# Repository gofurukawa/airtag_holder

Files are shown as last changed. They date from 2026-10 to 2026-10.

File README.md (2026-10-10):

# AirTag Umbrella Holder for AMVEL pentagon LARGE

AMVEL の超軽量折りたたみ傘 [pentagon LARGE](https://www.umbrella-store.net/products/pentagon-large)（[pentagon シリーズ](https://www.umbrella-store.net/collections/pentagon-series)）の持ち手の端に、AirTag を固定するための 3D プリント用ホルダーです。

持ち手の端にある円盤を左右 2 つのパーツで挟み込み、その下に AirTag を収め、窓あきのキャップをねじ込んで全体を固定します。

> [!NOTE]
> AMVEL 社とは関係のない非公式の自作パーツです。寸法は手元の 1 本を実測した値で、ロットや他モデル（pentagon72 / pentagon67 など）では合わない可能性があります。

## 構造

使用時の向き（上が生地側）で、上から次の順に重なります。

| 部品 | 役割 |
| --- | --- |
| 挟みパーツ A / B | 持ち手の円盤を左右から抱き込む。上端の爪でリム上端を押さえ、下部の外周におねじ |
| AirTag | 円盤の下のポケットに収納 |
| キャップ | めねじで本体にねじ込み、左右パーツを一体化。下向きの窓（Ø26）から AirTag が見え、音も抜ける |

設計上のポイントは次のとおりです。

- 円盤上面の凹みは、傘を畳むときに骨の連結部分が収まる場所なので、ふさがないようにしています。爪はリムの上端（幅約 1.35mm）だけを押さえ、凹みの開口 Ø26.8 はそのまま残ります。
- 円盤の底面は中央に向けてなだらかに膨らんでいます。実物は半径約 28mm の球面で、縁には幅約 1.5mm の平らな肩があります。空洞の底はそれよりわざと浅い球面（R33.7、縁の角と中央を通る球面）にしていて、円盤は爪・縁の角・中央の 3 か所で支えます。中央から縁の手前までに残る 0.5〜0.8mm のくさび形の空間は、印刷誤差と持ち手の個体差を吸収する余白です。実物の肩まで再現すると、空洞が設計より 0.2mm ほど狭く出るプリンタでは当たります。
- シャフト上の凹み（円盤上面から 13.5mm）や伸縮ロックのボタン（同 29.0mm）にはかかりません。
- 窓が下を向くので、入り込んだ雨水は自然に抜けます。
- 挟みパーツは合わせ面を下にして印刷するので、内側の空洞は横倒しのアーチになります。アーチの頂上（合わせ面から最も遠い所）は、45°の屋根と、元の円より 0.6mm 外側の平らな天井に置き換えています。この天井は両端が支えられた短い橋（ブリッジ）なので、サポートなしで印刷できます。少したれても、0.6mm の逃げの中に収まれば空洞には入り込みません。円盤と AirTag は、屋根の斜面と残りの円周で位置が決まります。

組み付け後の外形は、最大 Ø43.7mm、全高は約 22.5mm（円盤より下に約 11mm、上に 2mm）です。

## ファイル

| ファイル | 内容 |
| --- | --- |
| `airtag_umbrella_holder.scad` | OpenSCAD のソース。寸法はすべて変数 |
| `half_a.stl` | 挟みパーツ A（印刷向きに配置済み） |
| `half_b.stl` | 挟みパーツ B（印刷向きに配置済み） |
| `cap.stl` | キャップ（印刷向きに配置済み） |

## 実測値（モデルの基準寸法）

| 記号 | 箇所 | 値 |
| --- | --- | --- |
| A | 円盤の外径 | 29.5 mm |
| B | 円盤の厚み | 縁 5.6 mm / 中央 9.0 mm（底が膨らんでいる） |
| C | 凹みの内径（リム内径） | 26.8 mm |
| D | 凹みの深さ | 縁 4.6 mm〜（中央ほど深い） |
| — | 底面のふくらみ | 球面半径 約 28 mm。縁に幅約 1.5 mm の平らな肩（試し刷り品との隙間に名刺 0.5mm が入り 0.8mm が入らないこと、肩の幅から推定） |
| E | シャフト径 | 7.7 mm |
| — | リムの厚み | 約 1.35 mm |

## 部品の主な寸法

| 項目 | 値 |
| --- | --- |
| 爪の内径 | Ø26.8 mm |
| 円盤の空洞 | Ø29.9 mm、底は R33.7 の球面（片側 0.2mm のすき間）。縁と中央でぴったり固定できた実績のある値 |
| AirTag ポケット | Ø32.4 × 深さ 8.3 mm |
| 空洞の天井の逃げ | 45°の屋根＋元の円より 0.6 mm 外側の平らな天井（合わせ面と垂直な向きだけ） |
| ねじ | 台形ねじ Ø39 × ピッチ 3 mm、山の高さ 1.5 mm |
| キャップの窓 | Ø26 mm |
| 位置決めピン | Ø1.75 mm（フィラメント流用）× 2 本 |

## Mac で使うソフトウェア

### OpenSCAD（.scad を開いて寸法を調整する）

```sh
brew install --cask openscad@snapshot
```

正式版（2021.01）でも動きますが、ねじ山を含むこのモデルではレンダリング（F6）に数分かかります。開発版（snapshot）を入れ、Preferences → Advanced で Backend を **Manifold** にすると数秒で終わります。Apple Silicon にもネイティブ対応しています。

Homebrew の cask 名が変わっている場合は、[openscad.org](https://openscad.org/downloads.html) の Development Snapshots から直接ダウンロードしてください。

### スライサー（STL を確認して G-code にする）

| ソフト | 向いているプリンタ |
| --- | --- |
| [UltiMaker Cura](https://ultimaker.com/software/ultimaker-cura/) | Creality（Ender-3 S1 Pro など）、Ultimaker、汎用機 |
| [Bambu Studio](https://bambulab.com/download/studio) / [OrcaSlicer](https://github.com/SoftFever/OrcaSlicer) | Bambu Lab |
| [PrusaSlicer](https://www.prusa3d.com/page/prusaslicer_424/) | Prusa |

### インストール不要の確認方法

Finder で STL を選んでスペースキーを押すと、クイックルックで 3D プレビューを回して確認できます。

## STL の書き出し

OpenSCAD の GUI でカスタマイザーの `part` を切り替えて F6 → F7 で書き出すか、コマンドラインで次のように実行します。

```sh
# macOS（Homebrew cask）の場合、openscad コマンドはアプリ内にある
OPENSCAD=/Applications/OpenSCAD.app/Contents/MacOS/OpenSCAD

for p in half_a half_b cap; do
  "$OPENSCAD" -D "part=\"$p\"" -o "$p.stl" airtag_umbrella_holder.scad
done
```

アプリ名が `OpenSCAD-Nightly.app` などになっている場合は、パスを読み替えてください。

| `part` の値 | 出力 |
| --- | --- |
| `assembly` | 傘と AirTag のダミー入りの組み付け確認用 |
| `half_a` / `half_b` | 挟みパーツ（印刷向き） |
| `cap` | キャップ（印刷向き） |
| `print_all` | 3 部品を並べた状態 |

## 印刷設定（Creality Ender-3 S1 Pro + Cura 5.13 の例）

Cura のプロファイル「Standard Quality」を元に、次のように設定します。括弧内は Cura の英語表示の項目名で、設定パネル上部の検索欄に入れると見つかります。

| 設定 | 値 | 理由 |
| --- | --- | --- |
| ノズル径（Nozzle） | 0.4 mm | 標準 |
| 積層ピッチ（Layer Height） | 0.16 mm | ねじ山をなめらかにする |
| 壁の線数（Wall Line Count） | 4 | ねじ部（肉厚約 1.8mm）をほぼソリッドにする |
| インフィル密度（Infill Density） | 20%（初期値のまま） | 壁 4 本で部品のほとんどが埋まり、インフィルが入る所はほとんどない（下記） |
| サポート（Generate Support） | オフ | 3 部品ともサポートなしで印刷できる。オンにすると空洞の平らな天井の下にサポートが入る |
| ブリッジ設定（Enable Bridge Settings） | オン | Standard Quality では初期値がオフ。オンにすると、空洞の天井（ブリッジ）だけ速度と冷却を調整し、糸を張るように渡す |
| ブリッジのファン速度（Bridge Fan Speed） | 100% | ブリッジ設定をオンにすると表示される。渡した糸をすぐ固めて、たれを抑える |
| 初期層水平展開（Initial Layer Horizontal Expansion） | -0.1〜-0.2 mm | 1 層目がつぶれて広がり（エレファントフット）、合わせ面のふちが空洞側やねじ側へはみ出すのを防ぐ |
| 向き | STL のまま | 挟みパーツは合わせ面が下（ねじ山が上）、キャップは底面が下 |

- 挟みパーツは合わせ面を下にして印刷します。下を向く面は空洞の 45°の屋根と短い橋、ピン穴の小さな天井だけなので、サポートは要りません。合わせ面がベッドで平らに仕上がり、定着も安定します。
- この向きだと、ねじ山と爪にかかる力（ねじの軸方向）が積層面に沿うので、層間で割れにくくなります。
- ピン穴はベッドから垂直に立つ穴になり、真円に出ます。
- 空洞の天井は、PrusaSlicer 2.7 でスライスするとブリッジとして処理され、渡す長さは次のとおりでした。円盤の空洞は四方が囲まれているので、スライサーが短い向き（ねじの軸方向）を選びます。

  | 天井 | 渡す向き | 長さ |
  | --- | --- | --- |
  | AirTag ポケット | ねじの軸と直角 | 約 12 mm |
  | 円盤の空洞 | ねじの軸方向 | 約 6 mm |
  | 爪の開口 | ねじの軸と直角 | 約 10 mm |

- ブリッジの下面（空洞の内側）は糸が少したれたり波打ったりしますが、円盤や AirTag には触れない面なので、そのままで構いません。たれが 0.6mm を超えて円盤や AirTag が窮屈になるときは、`bridge_relief` を増やします（下の「調整」を参照）。
- キャップはサポートなしで印刷できます。
- インフィル密度はほぼ効きません。PrusaSlicer 2.7 で壁 4 本・インフィル 20% でスライスすると、インフィルの割合は使うフィラメントの 0.1%（挟みパーツ）と 5%（キャップ）でした。50% に上げても挟みパーツは変わらず、キャップが 4% 増えるだけです。
- 素材は、試し刷りなら PLA で十分です。常用するなら、熱や紫外線に強い PETG か ASA がおすすめです。PETG は PLA よりブリッジがたれやすいので、ブリッジの速度を落とすと安定します。

## 組み立て

1. 1.75mm フィラメントをニッパーで約 6mm に 2 本切り、バリを落とします。
2. 挟みパーツの片方の合わせ面にあるピン穴に、ピンを差し込みます。
3. 左右のパーツで持ち手の円盤を挟みます。
4. 下側のポケットに AirTag を入れます。
5. キャップをねじ込みます。キャップは本体の下端に突き当たって止まり、AirTag を押しつぶしません。

## 調整

試し刷りの結果に応じて、`.scad` の次の変数を変えてください。

| 症状 | 変数 | 目安 |
| --- | --- | --- |
| キャップがきつい／緩い | `thread_clr`（初期値 0.35） | きつければ 0.45、緩ければ 0.25 |
| 円盤にはめるとガタつく／閉じない | `clr`（初期値 0.2）、`recess_d`（爪の内径） | 0.1 刻みで調整 |
| 空洞の底を実物の肩まで再現したい | `dome_R`（初期値 0 ＝ 自動で 33.7、平らな肩なし） | 28 にすると実物に近い球面と幅約 1.4mm の平らな肩になる。中央から縁の手前までのすき間が 0.3〜0.4mm に減るので、空洞が狭く出るプリンタでは当たることがある。当たるなら 30〜31 |
| 空洞の天井が大きくたれる | `bridge_relief`（初期値 0.6） | 0.8 まで増やせる（ねじの谷までの肉厚が 1.0mm に減る）。0 にすると真円に戻り、横倒しで印刷するときは天井にサポートが要る |
| ピンがきつい／抜ける | `pin_clr`（初期値 0.08） | きつければ 0.12、緩ければ 0.05 |
| AirTag がカタカタ鳴る | — | 厚さ 0.5mm 程度のシリコンシートを挟む |
| キャップが緩みやすい | `washer_gap`（初期値 1.0） | ねじ上端の段差に平ワッシャー状のシリコンパッキンを入れる |

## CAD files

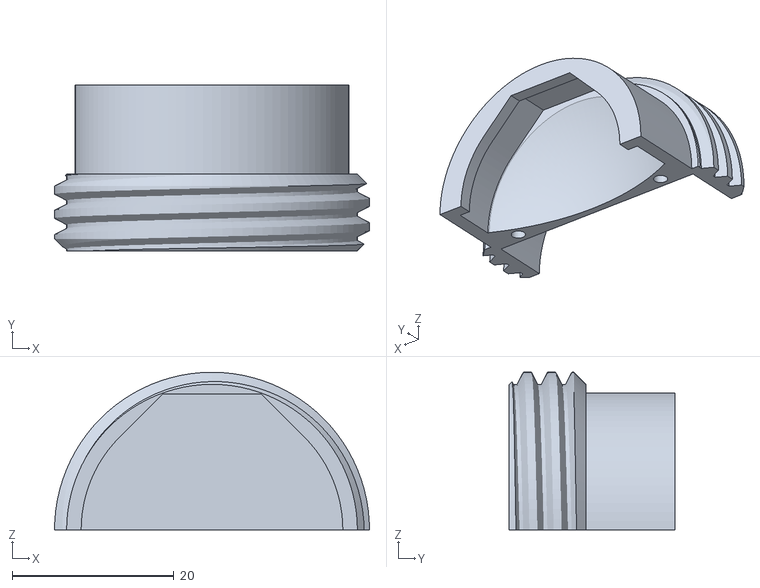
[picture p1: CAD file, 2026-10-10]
half_b.stl
39.0 x 20.5 x 19.5

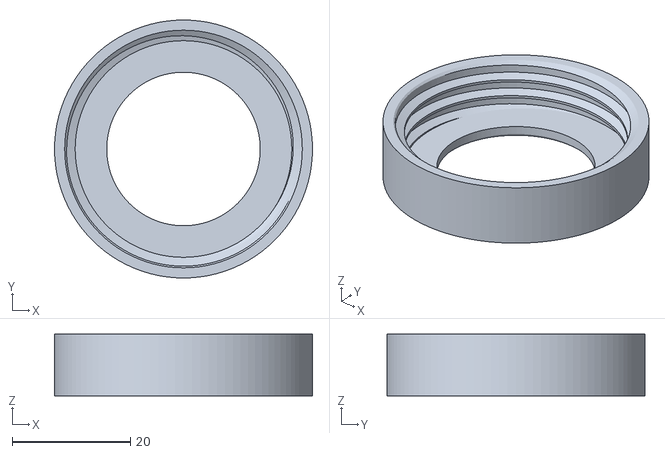
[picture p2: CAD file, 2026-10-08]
cap.stl
43.7 x 43.7 x 10.5

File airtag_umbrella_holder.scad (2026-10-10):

// =============================================================
//  AirTag umbrella holder（折りたたみ傘の握り端用）
//  使用時の向きでモデリング：+Z = 生地側、リム上端 = Z0
//  part を切り替えて STL を書き出す
// =============================================================

/* [出力する部品] */
part = "assembly"; // [assembly, half_a, half_b, cap, print_all]

/* [傘の実測値] */
disc_d        = 29.5;  // A 円盤の外径
recess_d      = 26.8;  // C 凹みの内径（リム内径）
disc_edge_h   = 5.6;   // B 縁での厚み（側面の平らな帯の高さ）
disc_center_h = 9.0;   // B 中央での厚み（底が膨らんでいる）
dome_R        = 0;     // 空洞の底の球面半径。0 なら縁と中央の厚みの差から自動（33.7、平らな肩なし＝実績のある形）。実物は約 28 で縁に幅約 1.5 の平らな肩があるが、再現すると印刷誤差で当たりやすい
shaft_d       = 7.7;   // E シャフト径（表示用）

/* [AirTag] */
airtag_d = 31.9;
airtag_h = 8.0;

/* [クリアランス] */
clr          = 0.2;   // 円盤まわりの片側すき間（0.2 で縁も中央もぴったり固定できた実績あり）
pocket_clr_d = 0.5;   // AirTag ポケットの直径方向すき間
pocket_clr_h = 0.3;   // AirTag ポケットの高さ方向すき間
thread_clr   = 0.35;  // ねじの半径方向すき間
thread_aclr  = 0.2;   // ねじの軸方向すき間（片側）

/* [本体] */
lip_h        = 2.0;   // 爪の上端高さ（リム上端から）
upper_wall   = 2.0;   // 円盤まわりの肉厚
partition_t  = 1.0;   // 円盤と AirTag の仕切り（中央の厚み）

/* [ねじ] */
thread_major_d = 39;
thread_pitch   = 3;
thread_depth   = 1.5;
crest_w        = 1.0;  // 山頂の幅
root_w         = 2.6;  // 山の根元の幅（< ピッチ）

/* [キャップ] */
cap_wall   = 2.0;
cap_floor  = 2.0;
window_d   = 26;
washer_gap = 1.0;  // キャップ上端と段差の間（パッキン用）

/* [位置決めピン（1.75mm フィラメントを流用）] */
pin_d     = 1.75;
pin_clr   = 0.08;
pin_depth = 3;
pin_x     = 12;

/* [印刷向き] */
// 挟みパーツは合わせ面を下にして印刷する。空洞の内面は横倒しのアーチになるので、
// 頂上（合わせ面から最も遠い所）を 45°の屋根と平らな橋に置き換え、たれが空洞に食い込まないようにする
bridge_relief = 0.6;  // 橋の高さ（元の円からの逃げ）。0 で真円のまま（頂上はサポートが要る）

/* [解像度] */
$fn = 96;

// ---------- 派生寸法 ----------
cavity_r       = disc_d / 2 + clr;
sag            = disc_center_h - disc_edge_h;
dome_R_eff     = dome_R > 0 ? dome_R : (pow(disc_d / 2, 2) + sag * sag) / (2 * sag);  // 自動なら縁の角を通る球面
cavity_bot_z   = -(disc_center_h + clr);   // 空洞の底（球面の頂点）
ledge_z        = -(disc_edge_h + clr);     // 球面が縁の平らな部分に移る高さ（自動の球面では縁の角に一致）
pocket_d       = airtag_d + pocket_clr_d;
pocket_h       = airtag_h + pocket_clr_h;
pocket_top_z   = cavity_bot_z - partition_t;
body_bot_z     = pocket_top_z - pocket_h;
upper_od       = 2 * cavity_r + 2 * upper_wall;
thread_top_z   = -disc_center_h;
thread_len     = thread_top_z - body_bot_z;
minor_d        = thread_major_d - 2 * thread_depth;
cap_od         = thread_major_d + 2 * thread_clr + 2 * cap_wall;
cap_inner_h    = thread_len - washer_gap;
cap_h          = cap_floor + cap_inner_h;

// 頂点 apex_z・半径 R の球面の、半径 r での高さ
function dome_z(r, apex_z, R) = apex_z + R - sqrt(R * R - r * r);
// 半径 r での空洞の底面（球面と縁の平らな部分の低い方）
function cavity_z_at(r) = min(dome_z(r, cavity_bot_z, dome_R_eff), ledge_z);
pin_z = (pocket_top_z + cavity_z_at(pin_x)) / 2;

// ---------- 円盤の形（回転断面） ----------
// 底面は頂点 apex_z・半径 R の球面。球面が edge_z に達した先は edge_z の平面で、
// 半径 r_max の側面を経て top_z まで。空洞と確認用ダミーの両方で使う
module disc_profile(apex_z, R, edge_z, r_max, top_z, n = 48) {
    sag  = edge_z - apex_z;
    r_sh = sag < R ? min(r_max, sqrt(R * R - (R - sag) * (R - sag))) : r_max;  // 球面と平面の境目
    polygon(concat(
        [for (i = [0 : n]) let (r = r_sh * i / n) [r, dome_z(r, apex_z, R)]],
        [[r_max, edge_z], [r_max, top_z], [0, top_z]]));
}

// ---------- らせんのねじ山 ----------
// z=0..length の範囲に、半径 r_in→r_out の台形断面の山を生成
module helix_ridge(r_in, r_out, w_in, w_out, pitch, length, fn = 96) {
    n = ceil((length / pitch + 2) * fn);
    pts = [for (i = [0 : n])
        let (a = 360 * i / fn, z = -pitch + pitch * i / fn, c = cos(a), s = sin(a))
        each [[r_in * c, r_in * s, z - w_in / 2],
              [r_out * c, r_out * s, z - w_out / 2],
              [r_out * c, r_out * s, z + w_out / 2],
              [r_in * c, r_in * s, z + w_in / 2]]];
    side = [for (i = [0 : n - 1]) for (j = [0 : 3])
        let (a = 4 * i + j, b = 4 * i + (j + 1) % 4,
             c = 4 * (i + 1) + (j + 1) % 4, d = 4 * (i + 1) + j)
        each [[a, d, c], [a, c, b]]];
    faces = concat([[0, 1, 2], [0, 2, 3]], side,
                   [[4 * n, 4 * n + 2, 4 * n + 1], [4 * n, 4 * n + 3, 4 * n + 2]]);
    polyhedron(pts, faces, convexity = 10);
}

module ext_thread() {
    // 両端を 45°で面取りしたおねじ
    intersection() {
        helix_ridge(minor_d / 2 - 0.05, thread_major_d / 2,
                    root_w, crest_w, thread_pitch, thread_len);
        rotate_extrude() polygon([
            [0, 0], [minor_d / 2, 0], [thread_major_d / 2 + 0.01, thread_depth],
            [thread_major_d / 2 + 0.01, thread_len - thread_depth],
            [minor_d / 2, thread_len], [0, thread_len]]);
    }
}

module int_thread_void(h) {
    // めねじの空間（すき間込み）
    w_in = root_w - (root_w - crest_w) * thread_clr / thread_depth + 2 * thread_aclr;
    w_out = crest_w + 2 * thread_aclr;
    union() {
        cylinder(d = minor_d + 2 * thread_clr, h = h);
        intersection() {
            helix_ridge(minor_d / 2 + thread_clr - 0.05, thread_major_d / 2 + thread_clr,
                        w_in, w_out, thread_pitch, h + 1);
            cylinder(r = cap_od, h = h);
        }
        // 入口の面取り
        translate([0, 0, h - thread_depth])
            cylinder(r1 = minor_d / 2 + thread_clr,
                     r2 = thread_major_d / 2 + thread_clr + 0.3, h = thread_depth + 0.01);
    }
}

// ---------- 横倒し印刷用の逃げ ----------
// 半径 r の円に、±Y（合わせ面から最も遠い向き）へ 45°の屋根を足し、r + bridge_relief で平らに切る
module relief_2d(r) {
    k = r * sqrt(2);  // 屋根の頂点
    intersection() {
        hull() {
            circle(r = r);
            square([0.01, 2 * k], center = true);
        }
        square([2 * k, 2 * (r + bridge_relief)], center = true);
    }
}

// ---------- 本体（分割前） ----------
module disc_cavity() {
    rotate_extrude() disc_profile(cavity_bot_z, dome_R_eff, ledge_z, cavity_r, clr);
}

module body() {
    difference() {
        union() {
            translate([0, 0, thread_top_z - 0.01])   // ねじ部と 0.01 重ねて、段差面での面の重なりを避ける
                cylinder(d = upper_od, h = lip_h - thread_top_z + 0.01);
            translate([0, 0, body_bot_z]) {
                cylinder(d = minor_d, h = thread_len);
                ext_thread();
            }
        }
        translate([0, 0, -1]) cylinder(d = recess_d, h = lip_h + 2);   // 爪の開口
        disc_cavity();                                                  // 円盤
        translate([0, 0, body_bot_z - 1]) cylinder(d = pocket_d, h = pocket_h + 1); // AirTag
        if (bridge_relief > 0) {                                        // 横倒し印刷用の逃げ
            translate([0, 0, body_bot_z - 1]) linear_extrude(pocket_h + 1) relief_2d(pocket_d / 2);
            translate([0, 0, ledge_z]) linear_extrude(clr - ledge_z) relief_2d(cavity_r);
            translate([0, 0, -1]) linear_extrude(lip_h + 2) relief_2d(recess_d / 2);
        }
        for (x = [-pin_x, pin_x])                                       // ピン穴
            translate([x, 0, pin_z]) rotate([90, 0, 0])
                cylinder(d = pin_d + 2 * pin_clr, h = 2 * pin_depth, center = true, $fn = 24);
    }
}

module half(side) {
    intersection() {
        body();
        translate([-50, side > 0 ? 0 : -100, -50]) cube([100, 100, 100]);
    }
}

module cap() {
    difference() {
        cylinder(d = cap_od, h = cap_h);
        translate([0, 0, -1]) cylinder(d = window_d, h = cap_floor + 2);
        translate([0, 0, cap_floor]) int_thread_void(cap_inner_h + 0.01);
        // 窓の外側の面取り
        translate([0, 0, -0.01]) cylinder(d1 = window_d + 1.2, d2 = window_d, h = 0.6);
    }
}

// ---------- 確認用のダミー ----------
module umbrella_dummy() {
    color("DimGray") {
        difference() {
            rotate_extrude() disc_profile(-disc_center_h, dome_R_eff, -disc_edge_h, disc_d / 2, 0);
            translate([0, 0, -4.6]) cylinder(d = recess_d, h = 5);
        }
        translate([0, 0, -5]) cylinder(d = shaft_d, h = 45);
    }
}

module airtag_dummy() {
    color("WhiteSmoke") translate([0, 0, body_bot_z + 0.15]) cylinder(d = airtag_d, h = airtag_h);
}

// ---------- 出力 ----------
// 印刷向き：挟みパーツは合わせ面を下（ねじ山が上）、キャップは底を下
body_h = lip_h - body_bot_z;
module print_half(side)
    rotate([side * 90, 0, 0])                                 // 合わせ面（y=0）を z=0 に
        translate([0, 0, -(body_bot_z + lip_h) / 2]) half(side);  // ねじの軸方向の中央を原点に

if (part == "assembly") {
    umbrella_dummy();
    airtag_dummy();
    color("MediumPurple", 0.85) translate([0, 4, 0]) half(1);
    color("SlateBlue", 0.85) translate([0, -4, 0]) half(-1);
    color("MediumSeaGreen") translate([0, 0, body_bot_z - cap_floor - 12]) cap();
} else if (part == "half_a") {
    print_half(1);
} else if (part == "half_b") {
    print_half(-1);
} else if (part == "cap") {
    cap();
} else if (part == "print_all") {
    translate([0, body_h / 2 + 3, 0]) print_half(1);
    translate([0, -body_h / 2 - 3, 0]) print_half(-1);
    translate([cap_od + 8, 0, 0]) cap();
}

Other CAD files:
half_a.stl

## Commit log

2026-10-05 Add AirTag umbrella holder SCAD model, STL files and README
    [airtag_umbrella_holder.scad, cap.stl, half_a.stl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]
2026-10-08 円盤の空洞を球面＋肩で定義できるようにし、実測を記録する（形状は main と同じ） (#2)
    * Shape the disc cavity as an R26 dome with a flat rim ledge
    The cavity floor was a sphere derived only from the 3.4 mm difference
    between the centre and edge thickness (R = 33.7 mm), which made it far
    flatter than the real handle and V-shaped in section. Tracing the
    silhouette in a photo of the handle shows the underside is a sphere of
    about R26 up to a radius of roughly 13 mm, then a flat shoulder out to
    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
    [airtag_umbrella_holder.scad, cap.stl, half_a.stl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]
2026-10-10 挟みパーツを合わせ面を下にした向きで出力し、サポートなしで印刷できるようにする (#3)
    * 挟みパーツを合わせ面を下にした向きで出力し、サポートなしで印刷できるようにする
    - print_half を合わせ面（y=0）が下、ねじ山が上になるよう回転
    - 横倒しになる空洞（AirTag ポケット・円盤の空洞・爪の開口）の頂上に
    45°の屋根と平らな橋の逃げ（bridge_relief = 0.6）を追加
    - print_all の配置を新しい向きに合わせる
    - half_a.stl / half_b.stl を再生成し、README の印刷設定を更新
    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
    [airtag_umbrella_holder.scad, half_a.stl, half_b.stl]
2026-10-14 差し込み式の取っ手（アンカー＋網目の握り、試作）と取っ手付きキャップを追加する (#4)
    * T 字アンカー式の取っ手（試作）と取っ手付きキャップを追加する
    - 取っ手：横棒（35 × 10 × 3mm、両端はキャップのねじ穴に入る円弧）、
    窓を通る首 Ø10、握り Ø22 の円柱、先端は半球。キャップの下面から先端まで 70mm
    - 取っ手付きキャップ：底を 5mm にし、上面に横棒の溝（深さ 3mm）を彫る。
    取っ手なしでも AirTag ケースとして使える。通常のキャップはそのまま残す
    - 取っ手は横棒を下にした逆さの向きで出力し、サ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
2026-10-14 .DS_Store を gitignore に追加する (#5)
2026-10-14 README にパーツの分解図・組み上がり図・組み立ての動画を追加する (#6)
    * README にパーツの分解図・組み上がり図・組み立ての動画を追加する
    傘を差している向き（取っ手が下）で、挟みパーツ・AirTag・アンカー・取っ手付きキャップ・握りを並べた画像と、
    組み上がった画像、組み上がる様子の GIF / MP4 を images/ に置く。
    Claude-Session: https://claude.ai/code/session_012miQXpFjrLrsZKJDxCthq2
    * README の画像を作るスクリプトを render/ にまとめる
    画像と動画を render/images/ に移し、STL から作り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
2026-10-16 試し刷りの結果を受けて、はめあいを緩め、挟みパーツを縦向きに戻し、径を細くする (#7)
    * 試し刷りの結果を受けて、はめあいを緩め、挟みパーツを縦向きに戻し、径を細くする
    - ねじのすき間を半径 0.35→0.5、軸方向 0.2→0.25 に広げる（回すのがきつかった）
    - 握りの穴と横棒の溝のすき間を 0.2→0.3 に広げる（差し込みがきつかった）
    - 挟みパーツの印刷向きを、ねじの軸が縦・サポートありに戻す（見た目がきれいだった）。
    合わせ面を下にした向きは half_on_side = true で選べるようにし、bridge_relief はそのとき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
2026-10-16 AirTag のポケットを曲面にし、ねじを Ø37 に細くする (#8)
    * AirTag のポケットを曲面にし、ねじを Ø37 に細くする
    - ポケットの上下の角を R2.25（AirTag の縁の丸み R2.0 の見積り＋すき間）で埋める。
    ねじの谷との間の壁は、AirTag が一番太い高さ 3.8mm の帯だけが薄く、その上下は最大 3.1mm まで厚くなる
    - ねじの外径を Ø38 → Ø37 にし、キャップの外径を Ø42.2 → Ø41.2 にする（帯の壁 1.4 → 0.9mm）
    - 下の開口が AirTag より狭くなるので、AirTag は左右のパーツで円盤といっしょに挟んで閉じ込める
    - 試し刷り用に、挟みパーツ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
2026-10-16 AirTag の寸法の出典を、Apple の寸法図（一次情報）に差し替える (#9)
    - 出典を、Apple の Dimensional Drawings（airtag.pdf、2021-04-20）に差し替え、入手方法を書く
    - 紹介記事からの孫引きと、現行の Accessory Design Guidelines についての記述を削る
    - ポケット（角 R2.25）を寸法図の断面と比べた結果（どちらの面を下にしても、一番近い所ですき間 0.26 mm）を書く
    - 寸法図の注記（スピーカーの範囲 Ø25.75、アンテナのため金属を置かない範囲 Ø37.31）を書く
    - 図面の権利表示に従い、図面と断面の座標はリポジトリに載せず、リンクだけ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
2026-10-18 AirTag のポケットを寸法図の断面に沿わせ、キャップの壁を 1.2mm にする (#10)
    - ポケットの上下を、四分の一の楕円で AirTag に沿って狭める（下：高さ 4.35 × 幅 3.2、上：高さ 3.85 × 幅 6.6）。
    Apple の寸法図の断面を、白い面とステンレスの面のどちらを下にしても入るように包んだ形で、
    すき間は一番太い所のまわりで 0.25mm、それ以外で 0.4mm 以上
    - ねじの谷との間の壁が 1.0mm を切る帯を、高さ 5.1mm から 1.9mm に狭める（一番薄い所は 0.9mm のまま）
    - 下の開口は Ø27.9 → Ø26（キャップの窓と同じ）。窓より狭くならない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
